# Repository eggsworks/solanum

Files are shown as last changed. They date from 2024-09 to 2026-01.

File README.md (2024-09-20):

# Solanum

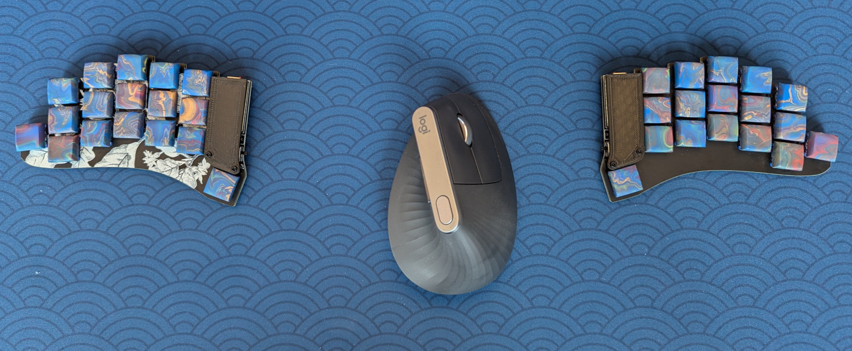
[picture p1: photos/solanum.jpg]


Solanum is a 34-key diodeless split keyboard based around Pro Micro compatible MCU modules. It features support for both wired and wireless builds and has been designed to be easily hand-assembled. The PCB is reversible and hotswap with support for Kailh Choc (v1) switches. 

## Features

The layout of Solanum differs from the typical 34-key split in that it has only one thumb key, and a reachy pinky key. Nominal key spacing is 19x18mm. All columns features a slight splay; the pinky columns are splayed more aggressively.

The top face of the switchplate (i.e., the face which is visible on the left hand side of the keyboard) features a botanical illustration of *Solanum melongena*, the eggplant.

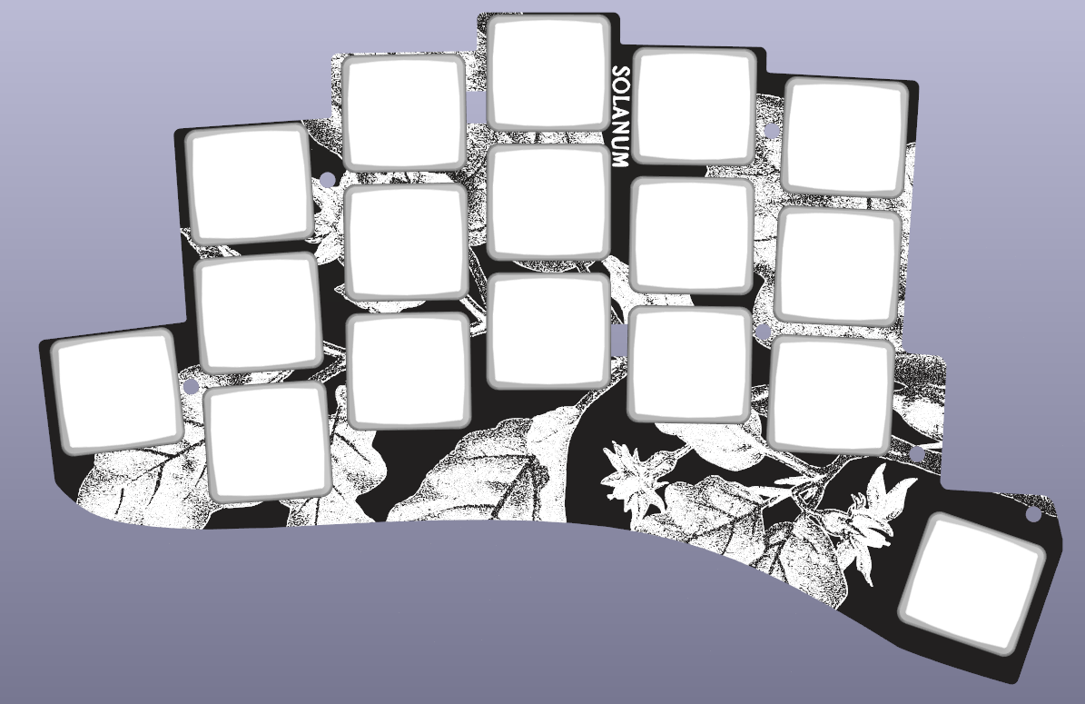
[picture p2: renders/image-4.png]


Solanum includes support for a splitkb.com tenting puck

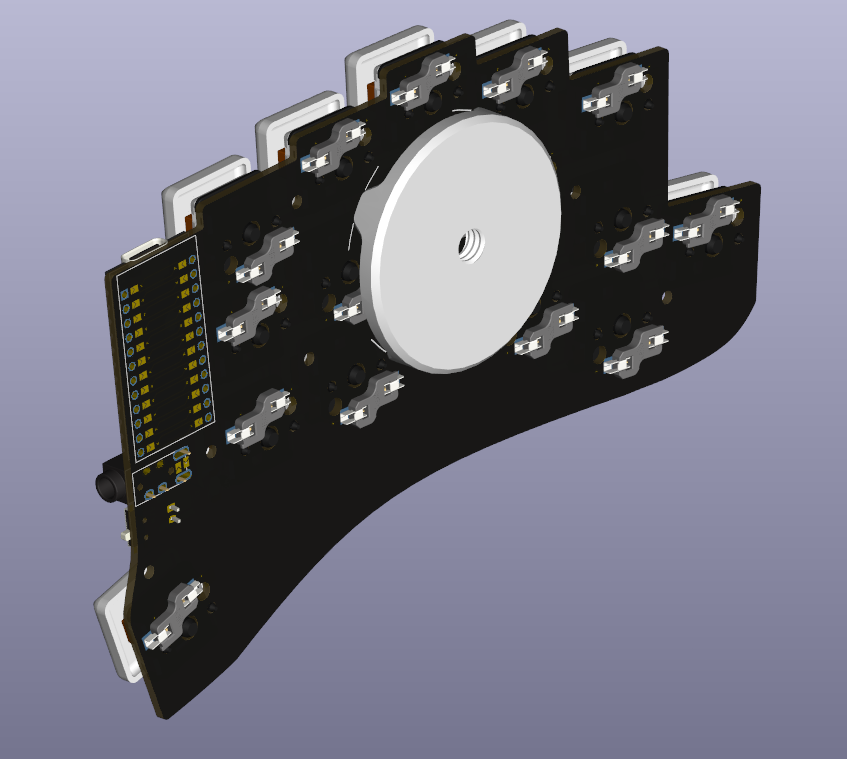
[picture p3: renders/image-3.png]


It features a TRRS port for wired builds, and
a dedicated battery JST and power switch for wireless builds.

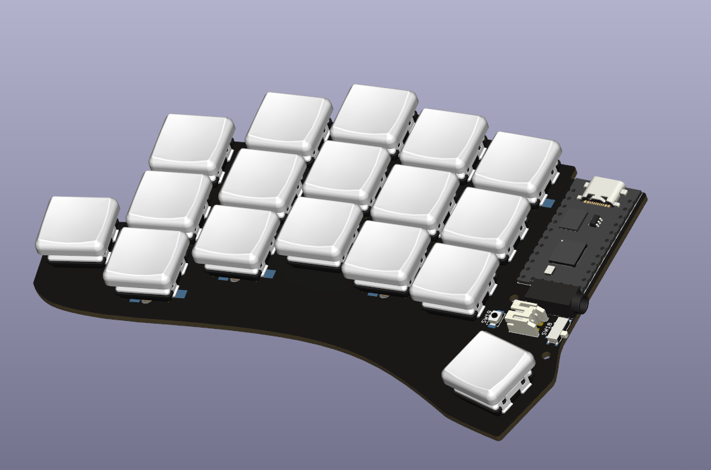
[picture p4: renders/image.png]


## BOM

- 2x PCB
- 2x switchplate
- 2x Pro Micro compatible MCU module
- 34x Kailh Choc hotswap sockets
- 34x Kailh Choc switches
- 34x 1u Choc keycaps
- 12x nylon M2 screws
- 12x nylon 1mm M2 washers
- 12x nylon M2 nuts

For wired build:
- 2x PJ-320A TRRS jack
- 1x TRRS cable

For wireless build:
- 2x JST S2B-PH-K-S
- 2x C&K OS102011MA1QN1

Optional:
- 2x splitkb tenting pucks
- 2x 3D printed MCU cover (from [extras/](extras/))
- 4x 6mm M2 standoffs

## Build guide

[https://docs.eggs.works/docs/build-guides/solanum/](https://docs.eggs.works/docs/build-guides/solanum/)

## Firmware

ZMK: https://github.com/eggsworks/zmk-config/

QMK: https://github.com/eggsworks/qmk_firmware/tree/solanum/keyboards/eggsworks/solanum

## License

Solanum is provided under the terms of the [GPL v3](LICENSE). The following portions are derived from other projects:

- Choc, Pro Micro, TRRS, and jumpers used on the JST footprint: [keyboard_reversible.pretty](https://github.com/50an6xy06r6n/keyboard_reversible.pretty) by 50an6xy06r6n (MIT License)
- Tenting puck: [tenting_puck](https://github.com/splitkb/tenting_puck) by splitkb.com (MIT License)
- JST, SPDT, and mounting holes: [KiCad footprint library](https://kicad.github.io/footprints/) (CC BY-SA 4.0)

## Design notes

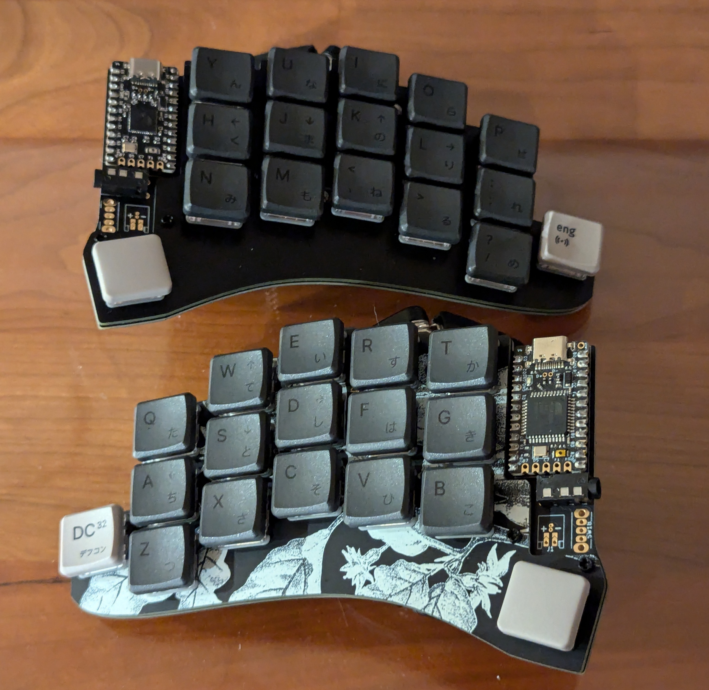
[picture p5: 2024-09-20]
photos/solanum_2.jpg

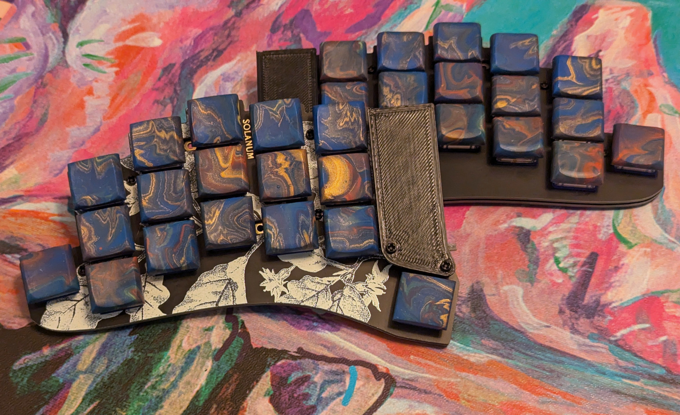
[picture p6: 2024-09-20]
photos/solanum_4.jpg

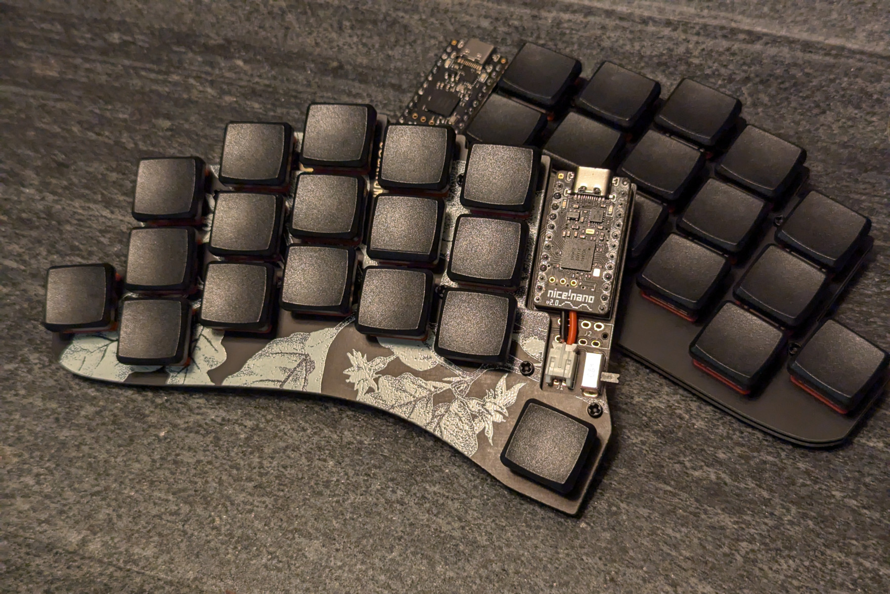
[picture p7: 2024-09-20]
photos/solanum_3.jpg

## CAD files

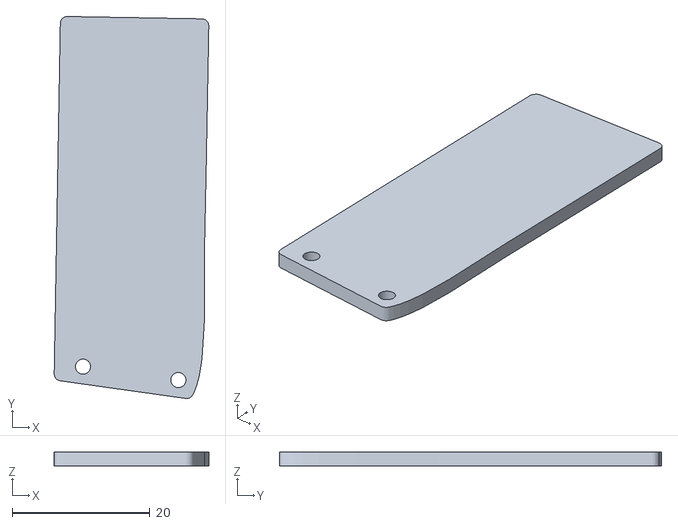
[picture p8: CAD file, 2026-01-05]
extras/mcu cover.stl
22.5 x 55.5 x 2.00

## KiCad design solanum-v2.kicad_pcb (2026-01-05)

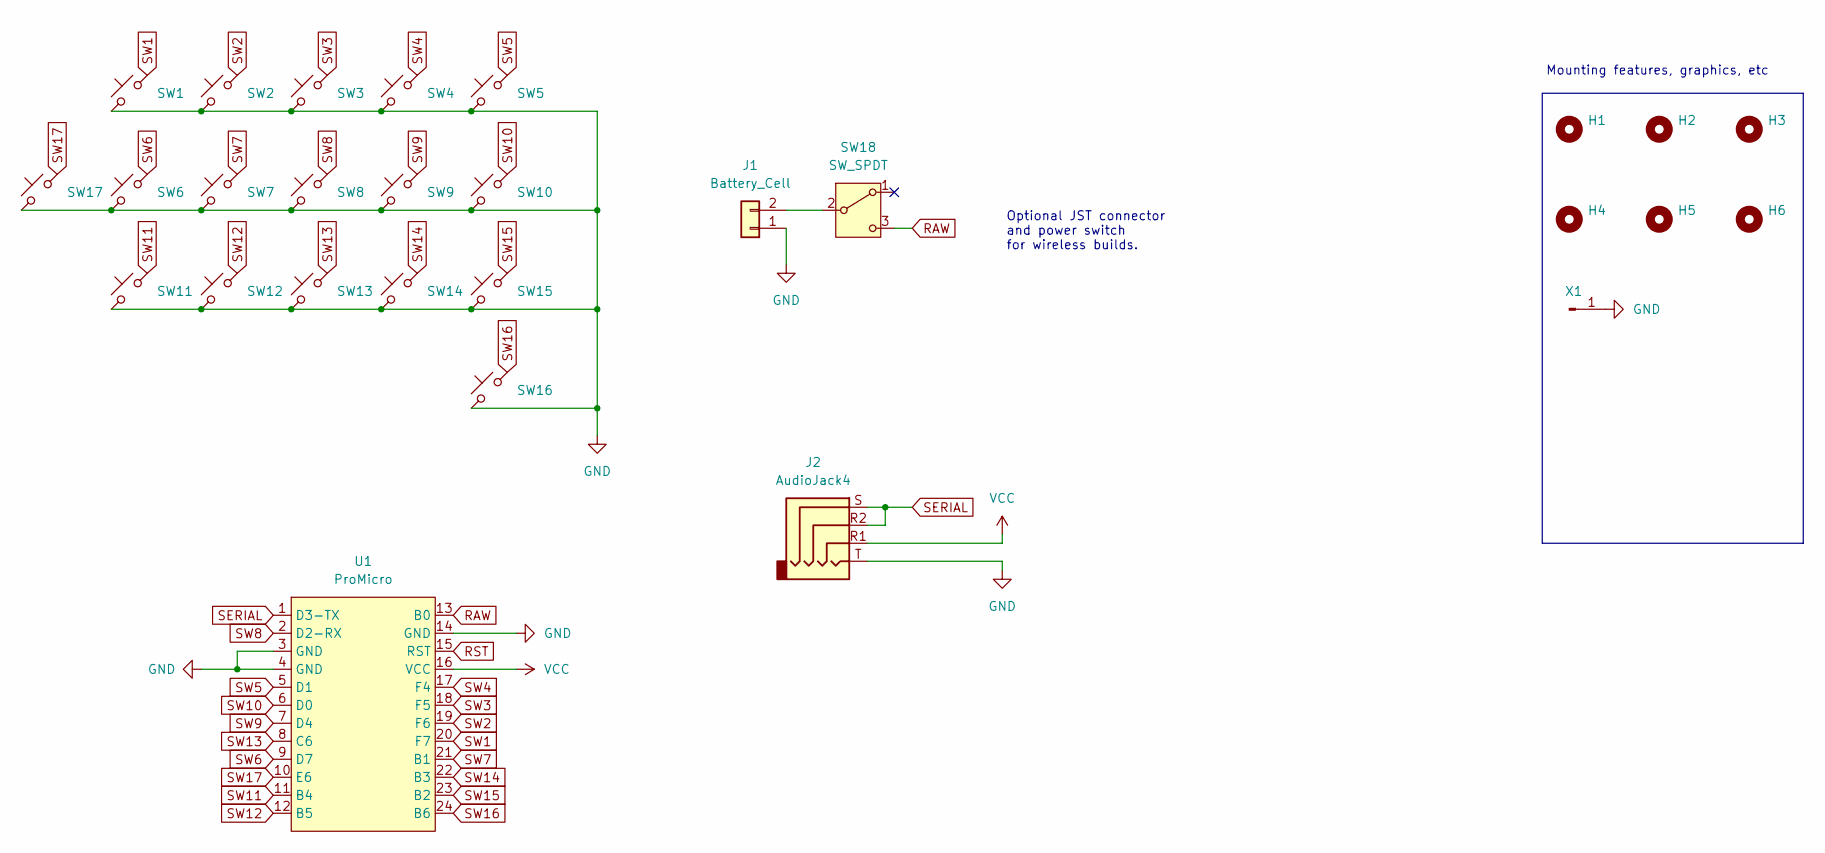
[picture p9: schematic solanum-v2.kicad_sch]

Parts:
H1, H2, H3, H4, H5, H6: MountingHole; MountingHole_2.2mm_M2
J1: Battery_Cell; JST_PH_S2B-PH-K_1x02_P2.00mm_Horizontal
J2: AudioJack4; PJ-320A
SW1, SW2, SW3, SW4, SW5, SW6, SW7, SW8, SW9, SW10, SW11, SW12, SW13, SW14, SW15, SW16, SW17: SW_Push_45deg; Choc_Hotswap
SW18: SW_SPDT; SW_SPDT_Shouhan_MSK12C02
U1: ProMicro
X1: Tenting puck; TentingPuck_NoHole

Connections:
GND: J1.1, J2.T, SW1.1, SW2.1, SW3.1, SW4.1, SW5.1, SW6.1, SW7.1, SW8.1, SW9.1, SW10.1, SW11.1, SW12.1, SW13.1, SW14.1, SW15.1, SW16.1, SW17.1, U1.3 (GND), U1.4 (GND), U1.14 (GND), X1.1
unnamed: J1.2, SW18.2 (B)
RAW: SW18.3 (C), U1.13 (B0)
RST: U1.15 (RST)
SERIAL: J2.R2, J2.S, U1.1 (D3-TX)
SW1: SW1.2, U1.20 (F7)
SW2: SW2.2, U1.19 (F6)
SW3: SW3.2, U1.18 (F5)
SW4: SW4.2, U1.17 (F4)
SW5: SW5.2, U1.5 (D1)
SW6: SW6.2, U1.9 (D7)
SW7: SW7.2, U1.21 (B1)
SW8: SW8.2, U1.2 (D2-RX)
SW9: SW9.2, U1.7 (D4)
SW10: SW10.2, U1.6 (D0)
SW11: SW11.2, U1.11 (B4)
SW12: SW12.2, U1.12 (B5)
SW13: SW13.2, U1.8 (C6)
SW14: SW14.2, U1.22 (B3)
SW15: SW15.2, U1.23 (B2)
SW16: SW16.2, U1.24 (B6)
SW17: SW17.2, U1.10 (E6)
VCC: J2.R1, U1.16 (VCC)

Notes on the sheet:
Optional JST connector and power switch for wireless builds.
Mounting features, graphics, etc

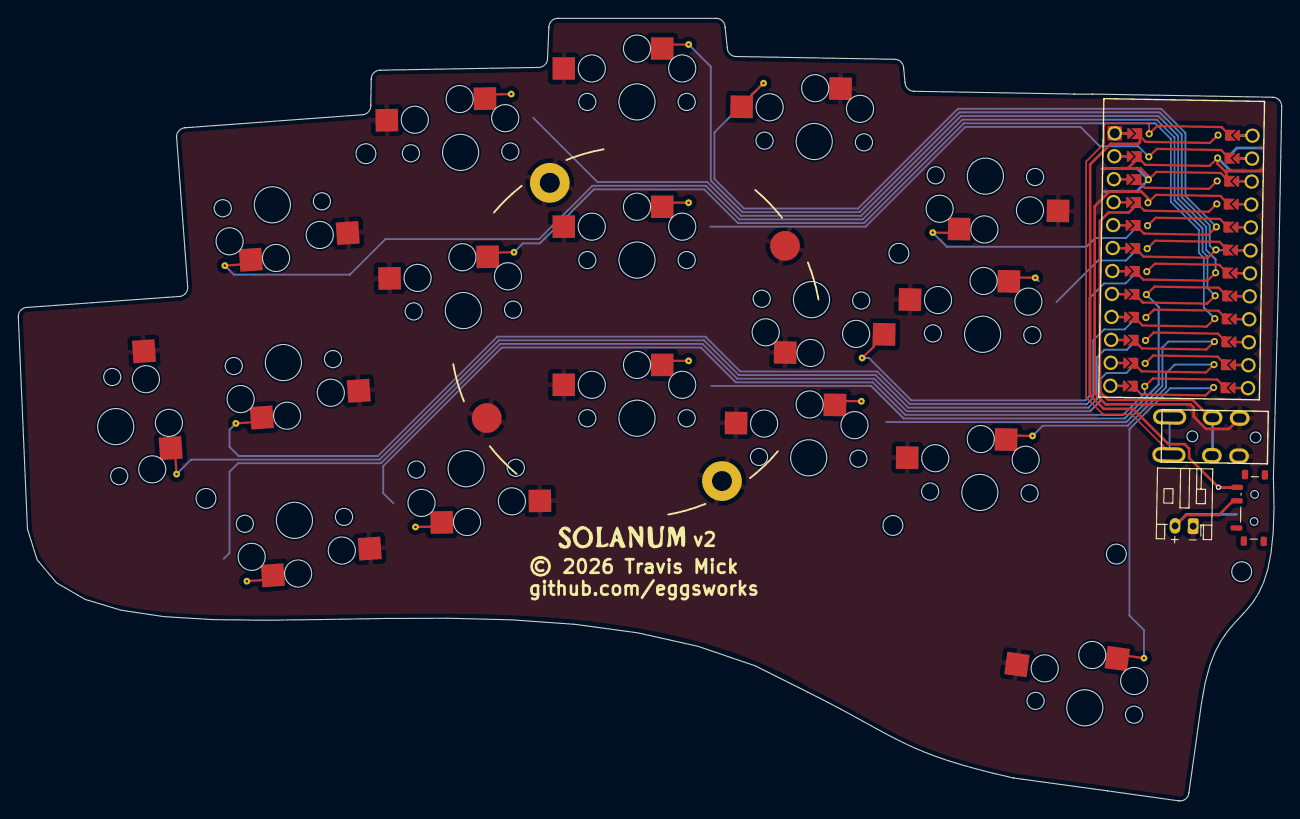
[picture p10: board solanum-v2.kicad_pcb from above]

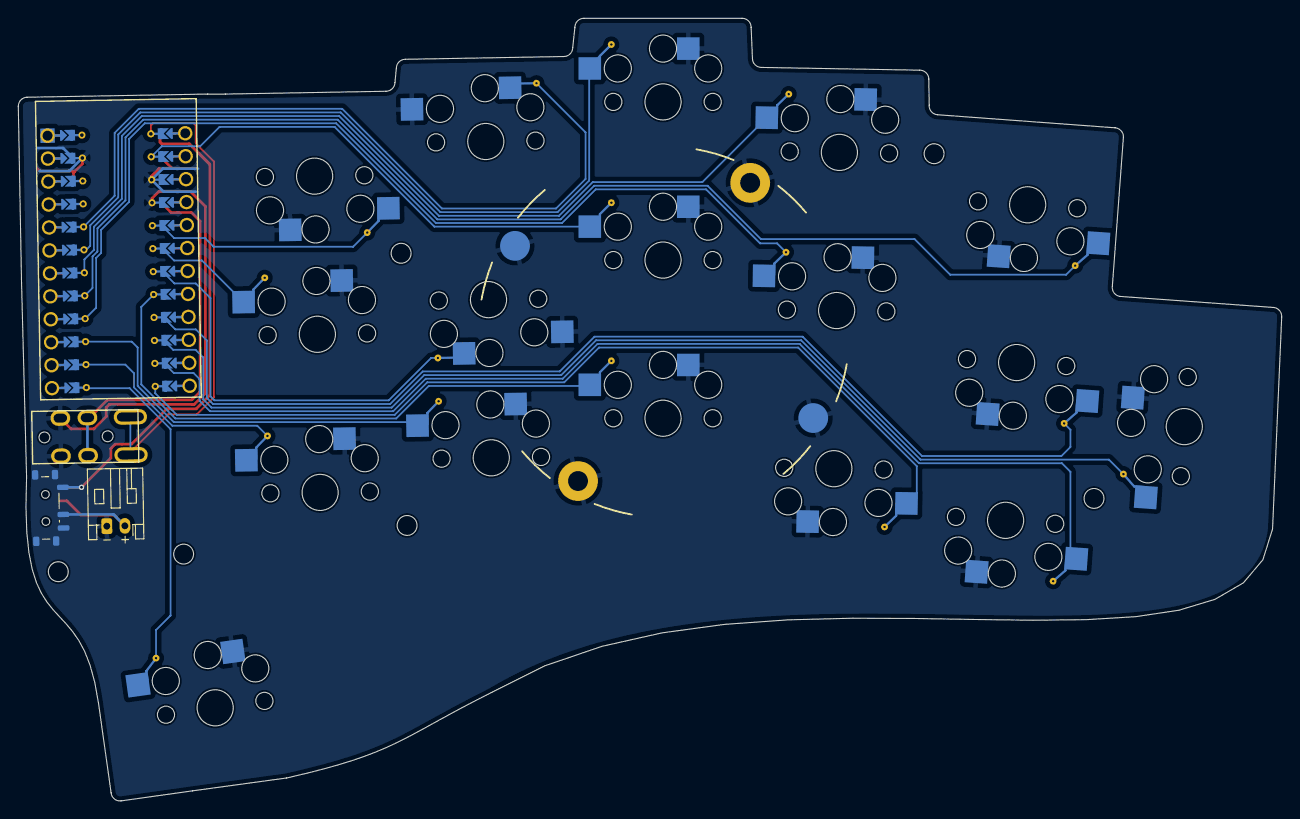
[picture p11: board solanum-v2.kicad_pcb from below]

Board: 2 copper layers, 139.8 x 86.6 mm, 28 parts (3 on the bottom side), 22 nets.

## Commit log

2024-09-20 Add MCU cover, update readme
    [mcu cover.stl]
2026-01-04 Rename files
    [egg34_plate.kicad_pcb, solanum-v2.kicad_pcb, solanum-v2.kicad_sch]
2026-01-05 progress on v2 pcb
    [solanum-v2.kicad_pcb, solanum-v2.kicad_sch]
2026-01-05 fine tuning
    [mcu cover.stl, solanum-v2.kicad_pcb, solanum-v2.kicad_sch]
2026-01-05 fixup switch footprint
    [solanum-v2.kicad_pcb]

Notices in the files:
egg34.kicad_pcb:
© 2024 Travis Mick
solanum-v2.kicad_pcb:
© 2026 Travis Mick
